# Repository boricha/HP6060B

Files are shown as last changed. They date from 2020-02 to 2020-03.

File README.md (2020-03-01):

# HP6060B
HP 6060B 3-60V/0-60A 300W SYSTEM DC ELECTRONIC LOAD  Graphic LCD Bridge
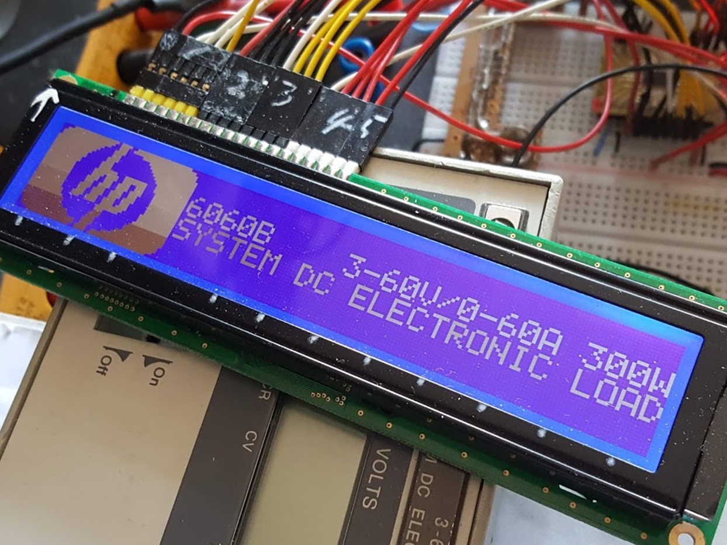
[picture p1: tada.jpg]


/*
 * $Id: main.c 3:06 PM 11/28/2019 ssk  $
 *
 * HP 6060B Graphic LCD .
 *
 * MIT License
 *
 * Copyright (c) 2019 ssk.
 *
 * Permission is hereby granted, free of charge, to any person obtaining a copy
 * of this software and associated documentation files (the "Software"), to deal
 * in the Software without restriction, including without limitation the rights
 * to use, copy, modify, merge, publish, distribute, sublicense, and/or sell
 * copies of the Software, and to permit persons to whom the Software is
 * furnished to do so, subject to the following conditions:
 *
 * The above copyright notice and this permission notice shall be included in all
 * copies or substantial portions of the Software.
 *
 * THE SOFTWARE IS PROVIDED "AS IS", WITHOUT WARRANTY OF ANY KIND, EXPRESS OR
 * IMPLIED, INCLUDING BUT NOT LIMITED TO THE WARRANTIES OF MERCHANTABILITY,
 * FITNESS FOR A PARTICULAR PURPOSE AND NONINFRINGEMENT. IN NO EVENT SHALL THE
 * AUTHORS OR COPYRIGHT HOLDERS BE LIABLE FOR ANY CLAIM, DAMAGES OR OTHER
 * LIABILITY, WHETHER IN AN ACTION OF CONTRACT, TORT OR OTHERWISE, ARISING FROM,
 * OUT OF OR IN CONNECTION WITH THE SOFTWARE OR THE USE OR OTHER DEALINGS IN THE
 * SOFTWARE.
 *
*/

<pre>
* The command was originally 10bits LSB First,
* but since the first 2 bits are always 0 and atmel SPI is 8bit system
* Accordingly 8Bits is used here
* +-----+--------------+------------------+---------------+
* |SYNC#|command field |10bit(originally) |8bit(used hear)|
* +-----+--------------+-----+------------+----------+----+
* |    0|Select LCD    |0x3f0|0b1111110000|0b11111100|0xfc|
* |    1|Unknown       |0x2e0|0b1011100000|0b10111000|0xb8|
* |    2|A Register    |0x028|0b0000101000|0b00001010|0x0a|
* |    3|B Register    |0x068|0b0001101000|0b00011010|0x1a|
* |    4|Annunciator   |0x2f0|0b1011110000|0b10111100|0xbc|
* |    5|C Register    |0x0a8|0b0010101000|0b00101010|0x2a|
* |    6|Display On/Off|0x320|0b1100100000|0b11001000|0xc8|
* +-----+--------------+------------------+---------------+
* Remembering that bits are transmitted from least significant bit (LSB) to most significant bit (MSB),
* aka. LSB First
</pre>

## Digial Waveform
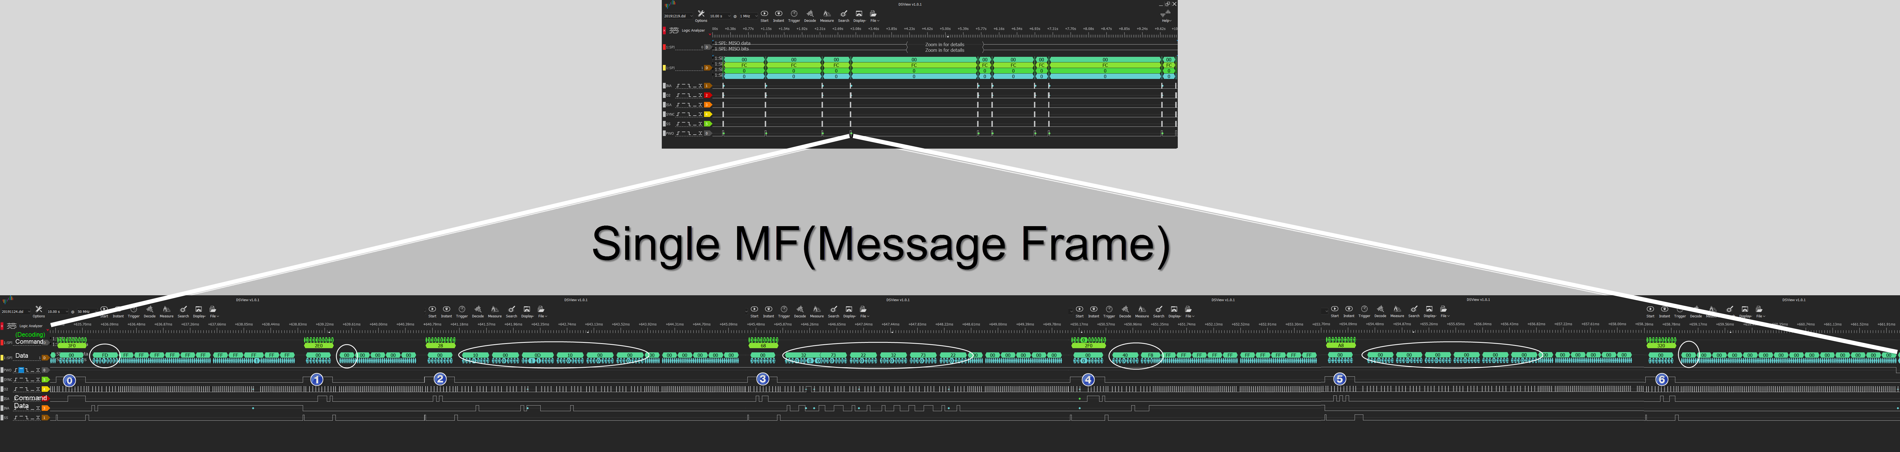
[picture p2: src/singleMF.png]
        
## Message Frame Structure(MF)
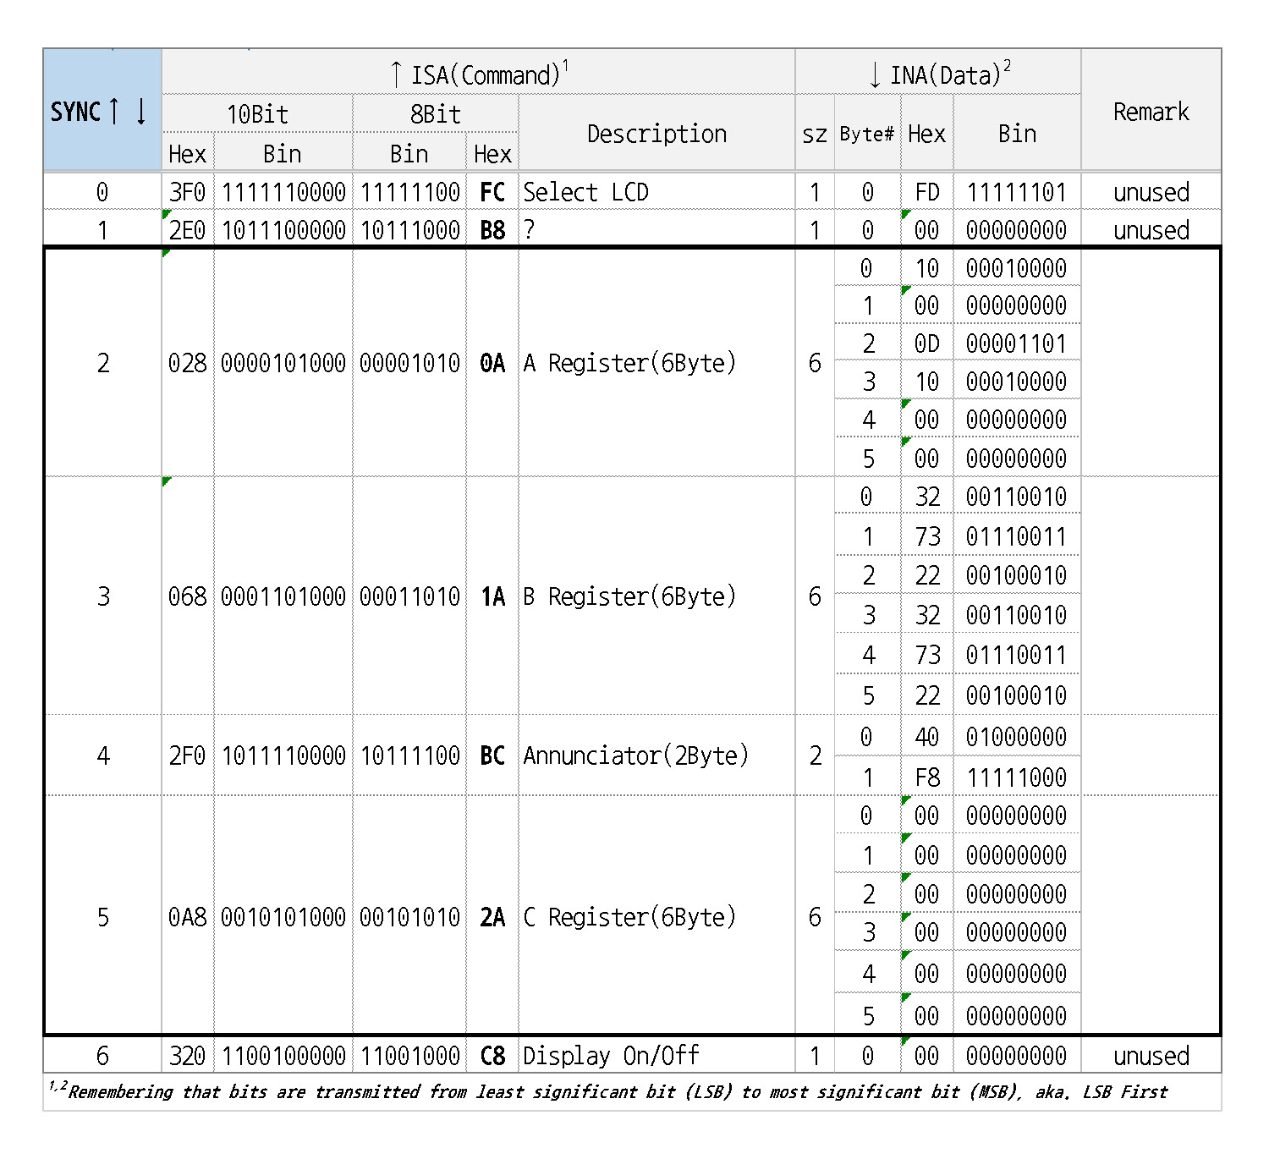
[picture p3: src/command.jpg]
   
## Modeling Event Based Behavior
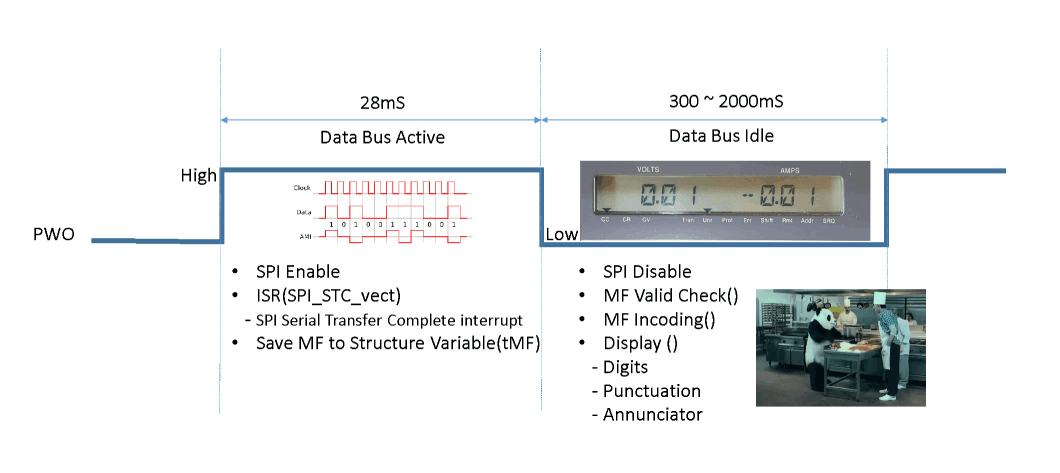
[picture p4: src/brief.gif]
   
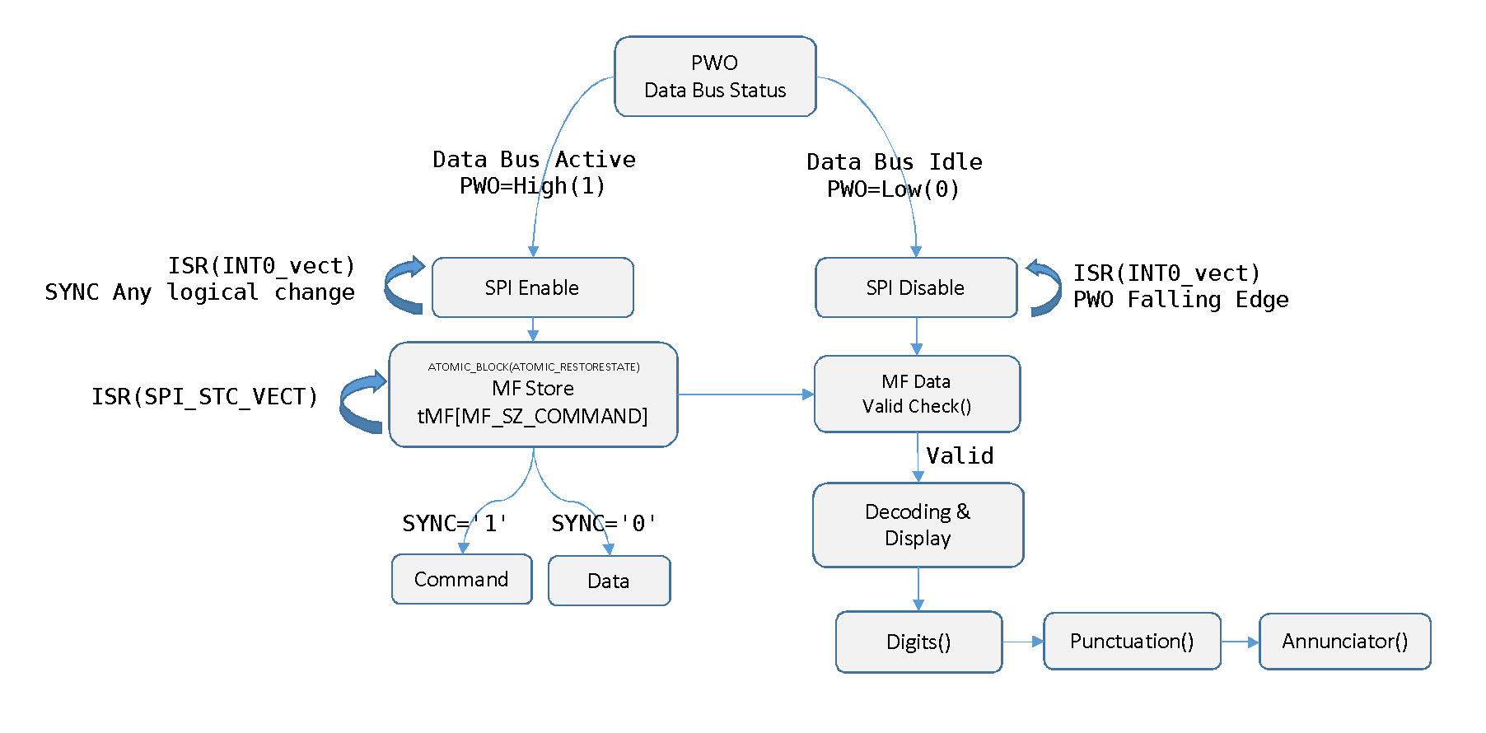
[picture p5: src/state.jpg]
   
## Schematics
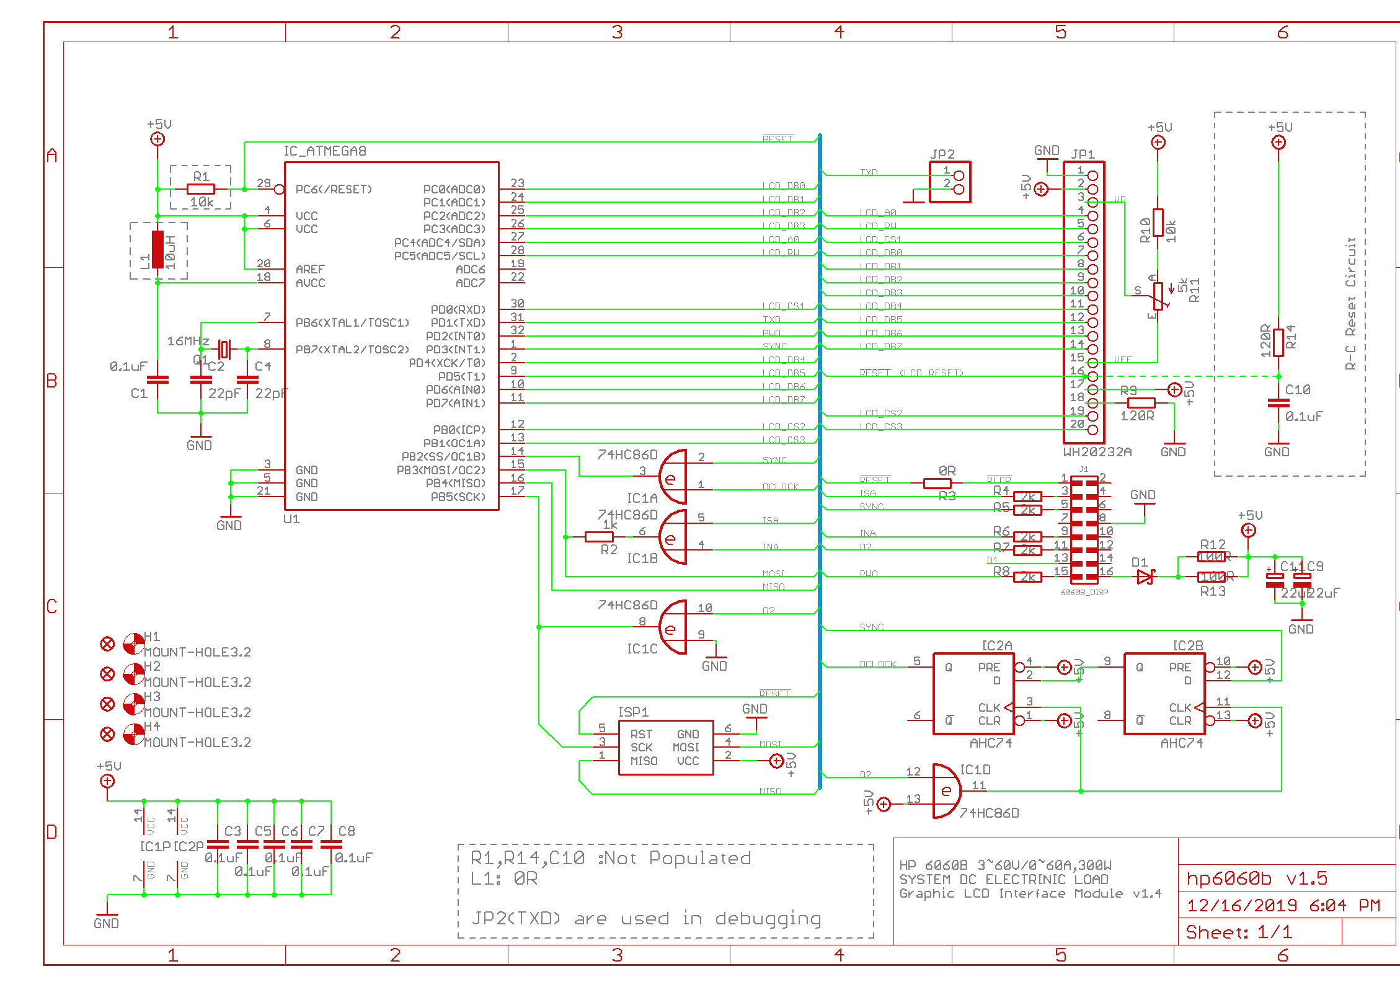
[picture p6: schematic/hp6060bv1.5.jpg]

## BOM(Bill of materials)
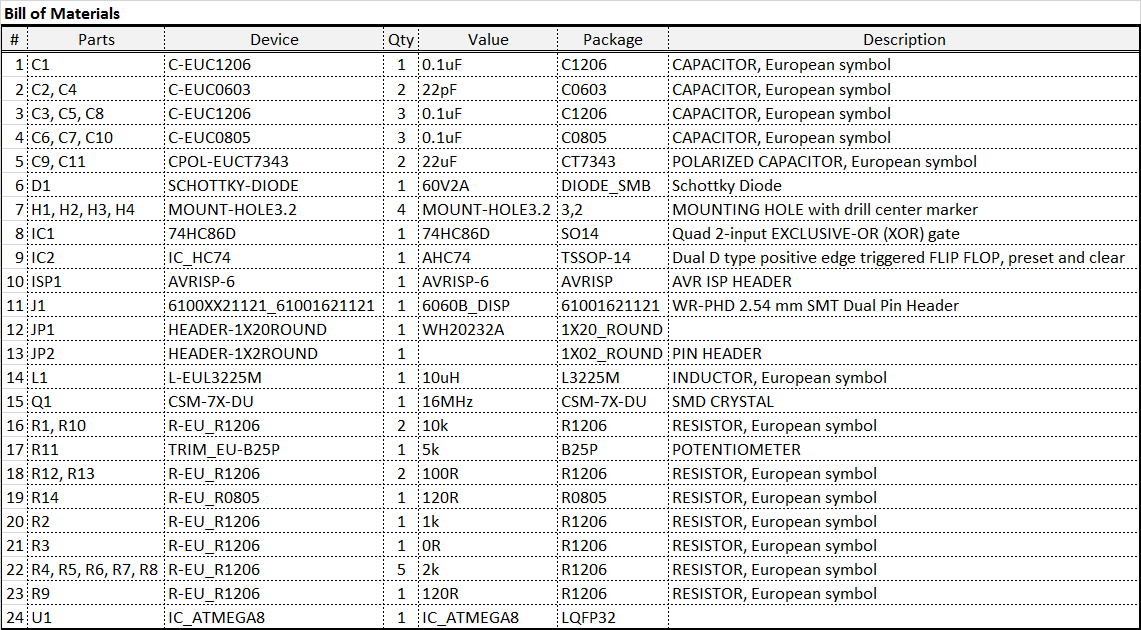
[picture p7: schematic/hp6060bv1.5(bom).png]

## PCB(top/bottom)
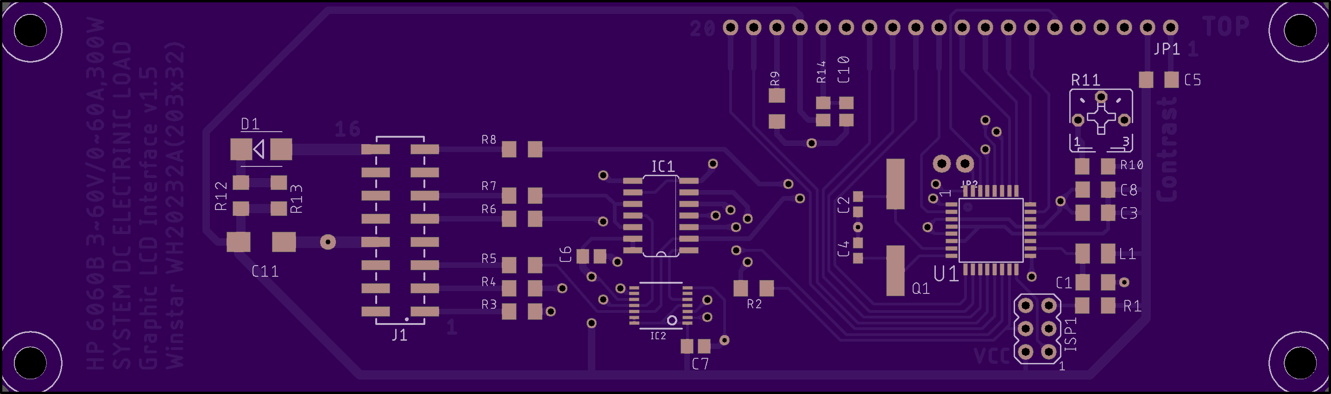
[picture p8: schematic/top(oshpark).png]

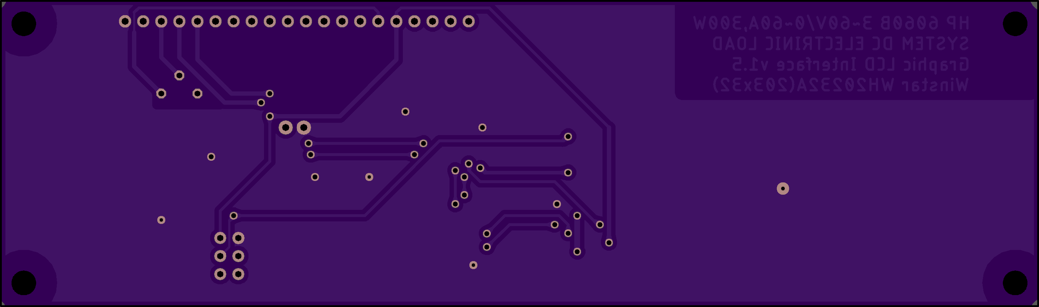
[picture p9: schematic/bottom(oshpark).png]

##
https://cafe.naver.com/carroty/337725
## Special thanks to: :+1: 
[LED display for HP 3457A multimeter - I did it :-)]<BR>
https://www.eevblog.com/forum/projects/led-display-for-hp-3457a-multimeter-i-did-it-)/ <BR>
I adapted this Aricle.  

述而不作.

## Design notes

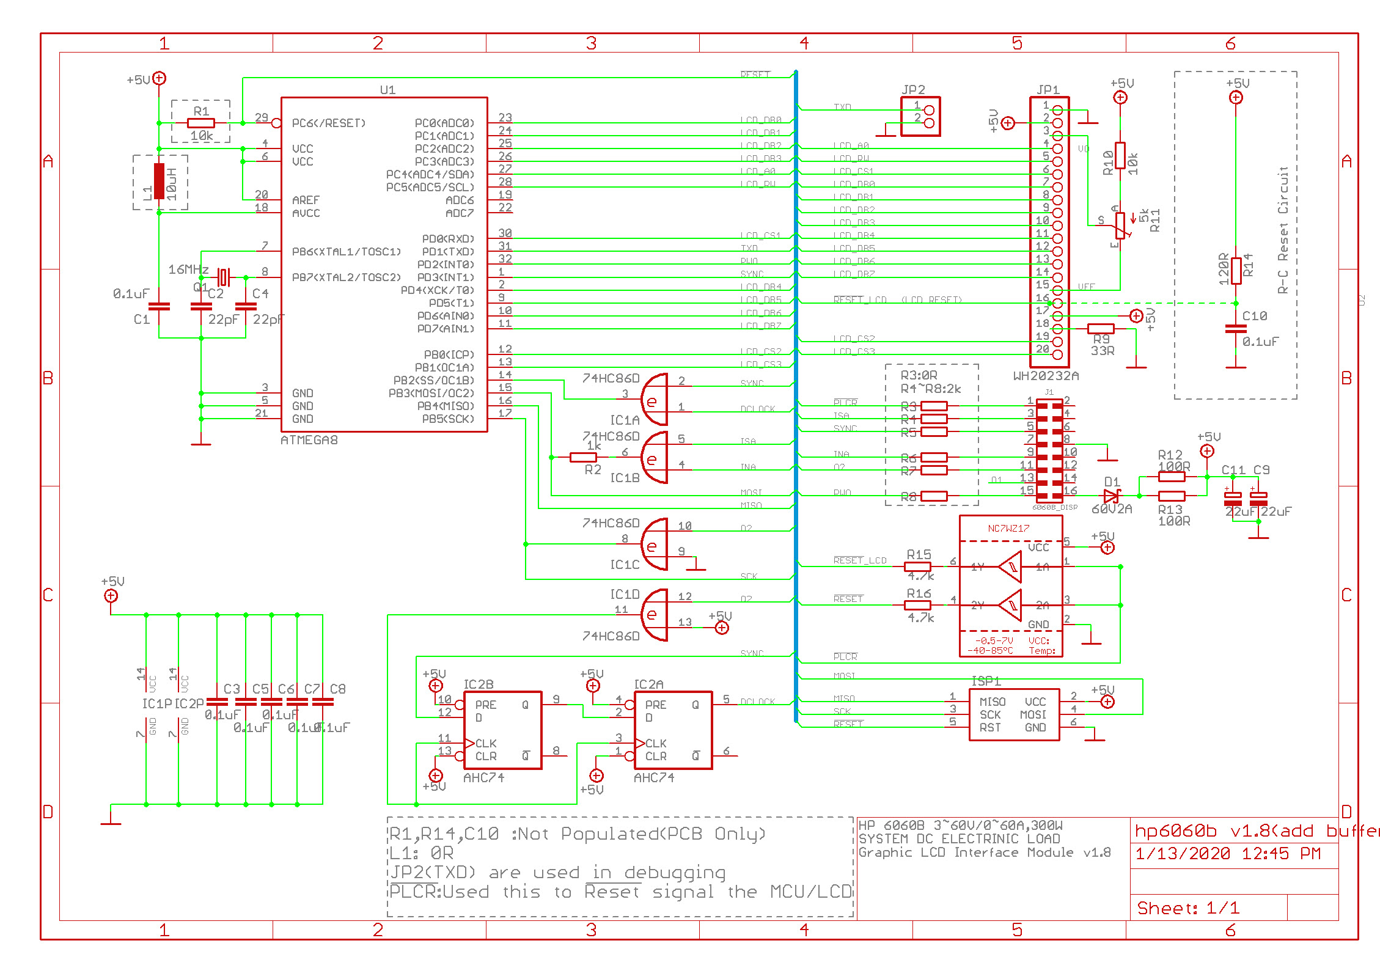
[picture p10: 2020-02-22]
schematic/hp6060bv1.8(add buffer).jpg

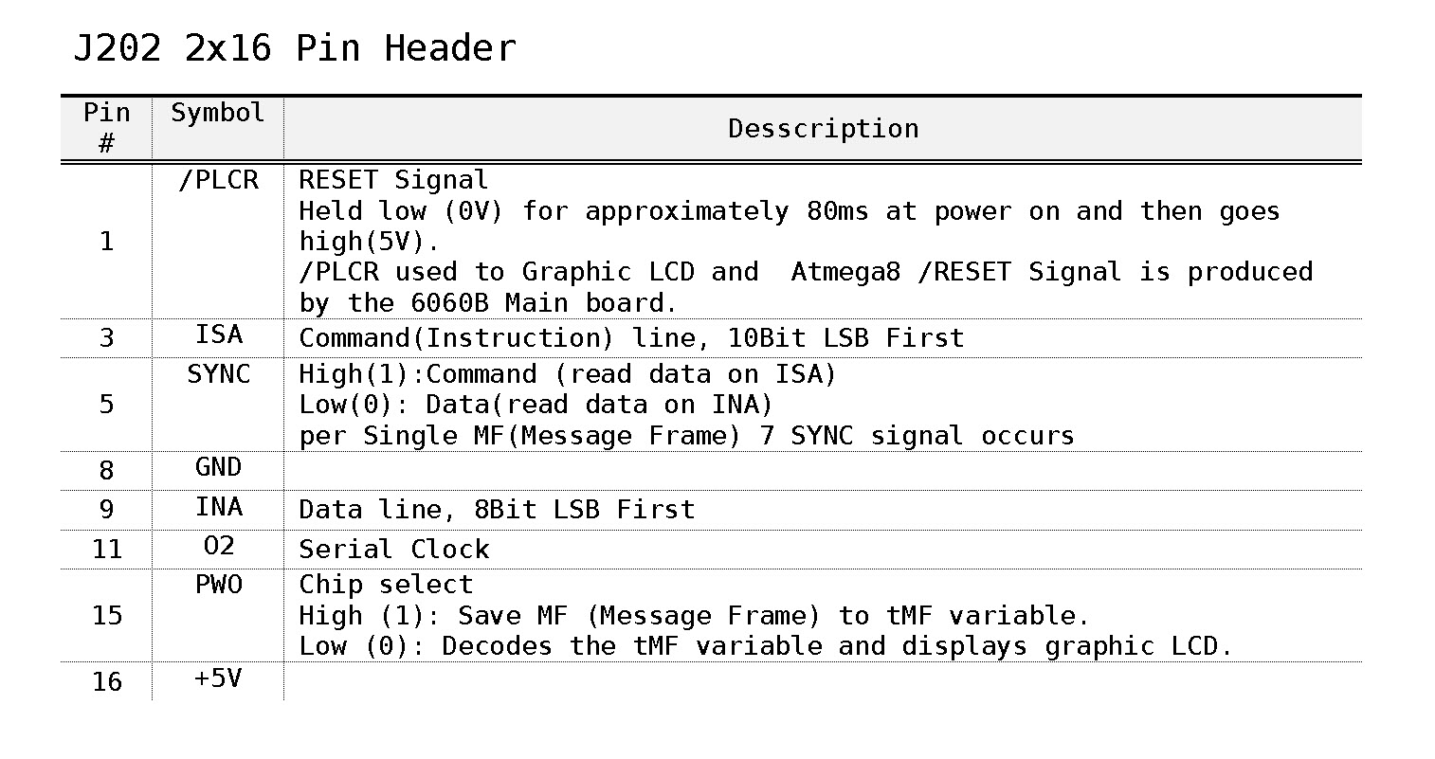
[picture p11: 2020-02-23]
src/pinout.jpg

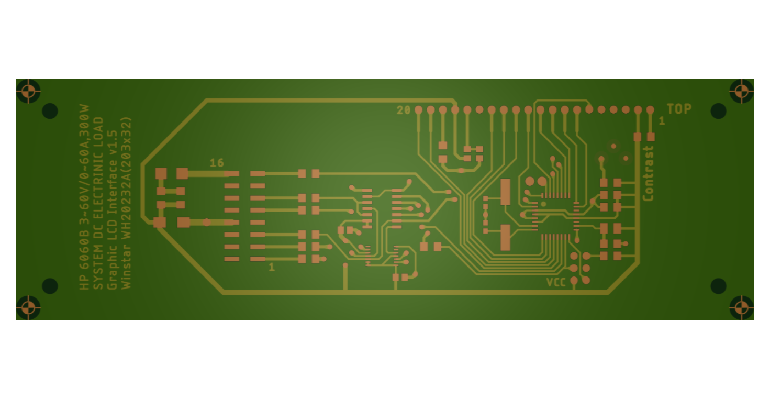
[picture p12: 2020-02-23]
schematic/top.png

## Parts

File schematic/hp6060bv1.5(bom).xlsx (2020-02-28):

Bill of Materials
# | Parts | Device | Qty | Value | Package | Description
1 | C1 | C-EUC1206 | 1 | 0.1uF | C1206 | CAPACITOR, European symbol
2 | C2, C4 | C-EUC0603 | 2 | 22pF | C0603 | CAPACITOR, European symbol
3 | C3, C5, C8 | C-EUC1206 | 3 | 0.1uF | C1206 | CAPACITOR, European symbol
4 | C6, C7, C10 | C-EUC0805 | 3 | 0.1uF | C0805 | CAPACITOR, European symbol
5 | C9, C11 | CPOL-EUCT7343 | 2 | 22uF | CT7343 | POLARIZED CAPACITOR, European symbol
6 | D1 | SCHOTTKY-DIODE | 1 | 60V2A | DIODE_SMB | Schottky Diode
7 | H1, H2, H3, H4 | MOUNT-HOLE3.2 | 4 | MOUNT-HOLE3.2 | 3,2 | MOUNTING HOLE with drill center marker
8 | IC1 | 74HC86D | 1 | 74HC86D | SO14 | Quad 2-input EXCLUSIVE-OR (XOR) gate
9 | IC2 | IC_HC74 | 1 | AHC74 | TSSOP-14 | Dual D type positive edge triggered FLIP FLOP, preset and clear
10 | ISP1 | AVRISP-6 | 1 | AVRISP-6 | AVRISP | AVR ISP HEADER
11 | J1 | 6100XX21121_61001621121 | 1 | 6060B_DISP | 61001621121 | WR-PHD 2.54 mm SMT Dual Pin Header
12 | JP1 | HEADER-1X20ROUND | 1 | WH20232A | 1X20_ROUND
13 | JP2 | HEADER-1X2ROUND | 1 |  | 1X02_ROUND | PIN HEADER
14 | L1 | L-EUL3225M | 1 | 10uH | L3225M | INDUCTOR, European symbol
15 | Q1 | CSM-7X-DU | 1 | 16MHz | CSM-7X-DU | SMD CRYSTAL
16 | R1, R10 | R-EU_R1206 | 2 | 10k | R1206 | RESISTOR, European symbol
17 | R11 | TRIM_EU-B25P | 1 | 5k | B25P | POTENTIOMETER
18 | R12, R13 | R-EU_R1206 | 2 | 100R | R1206 | RESISTOR, European symbol
19 | R14 | R-EU_R0805 | 1 | 120R | R0805 | RESISTOR, European symbol
20 | R2 | R-EU_R1206 | 1 | 1k | R1206 | RESISTOR, European symbol
21 | R3 | R-EU_R1206 | 1 | 0R | R1206 | RESISTOR, European symbol
22 | R4, R5, R6, R7, R8 | R-EU_R1206 | 5 | 2k | R1206 | RESISTOR, European symbol
23 | R9 | R-EU_R1206 | 1 | 120R | R1206 | RESISTOR, European symbol
24 | U1 | IC_ATMEGA8 | 1 | IC_ATMEGA8 | LQFP32

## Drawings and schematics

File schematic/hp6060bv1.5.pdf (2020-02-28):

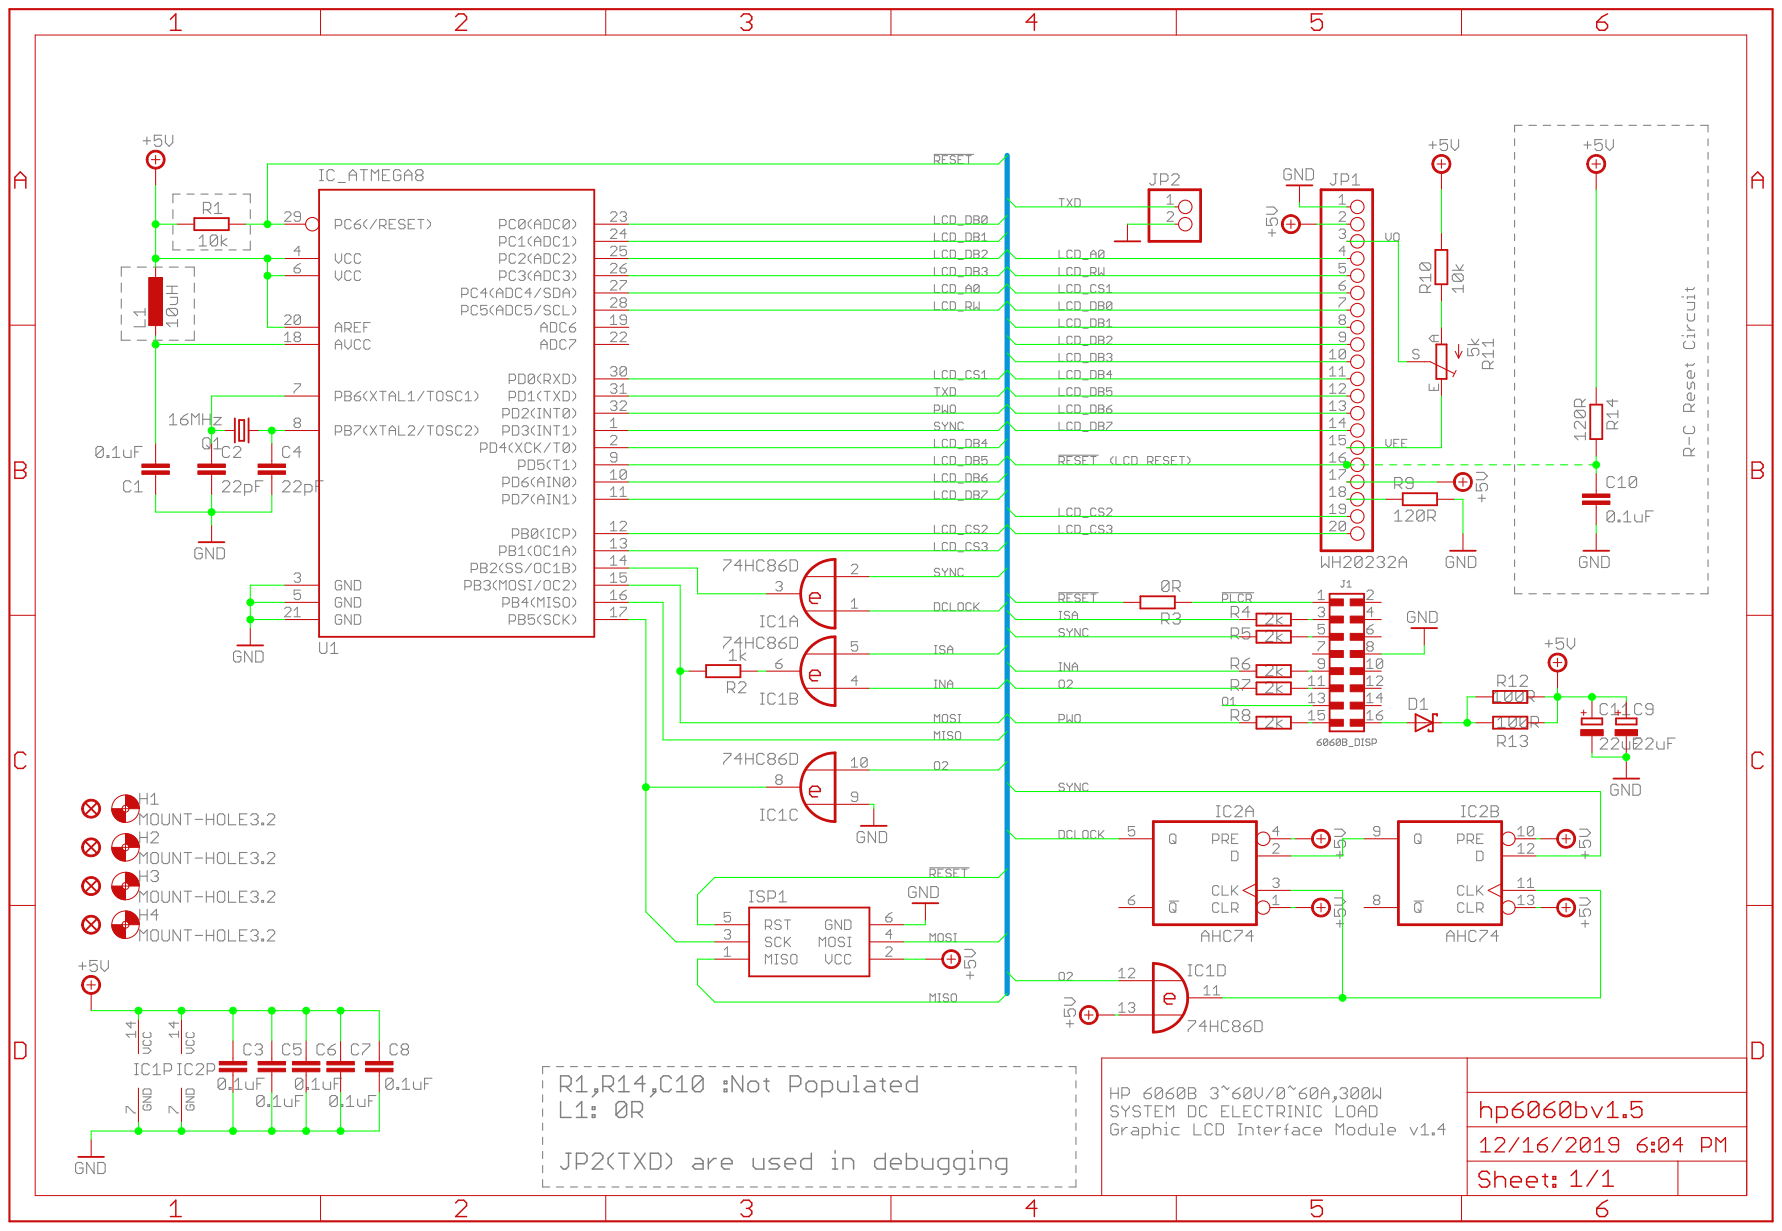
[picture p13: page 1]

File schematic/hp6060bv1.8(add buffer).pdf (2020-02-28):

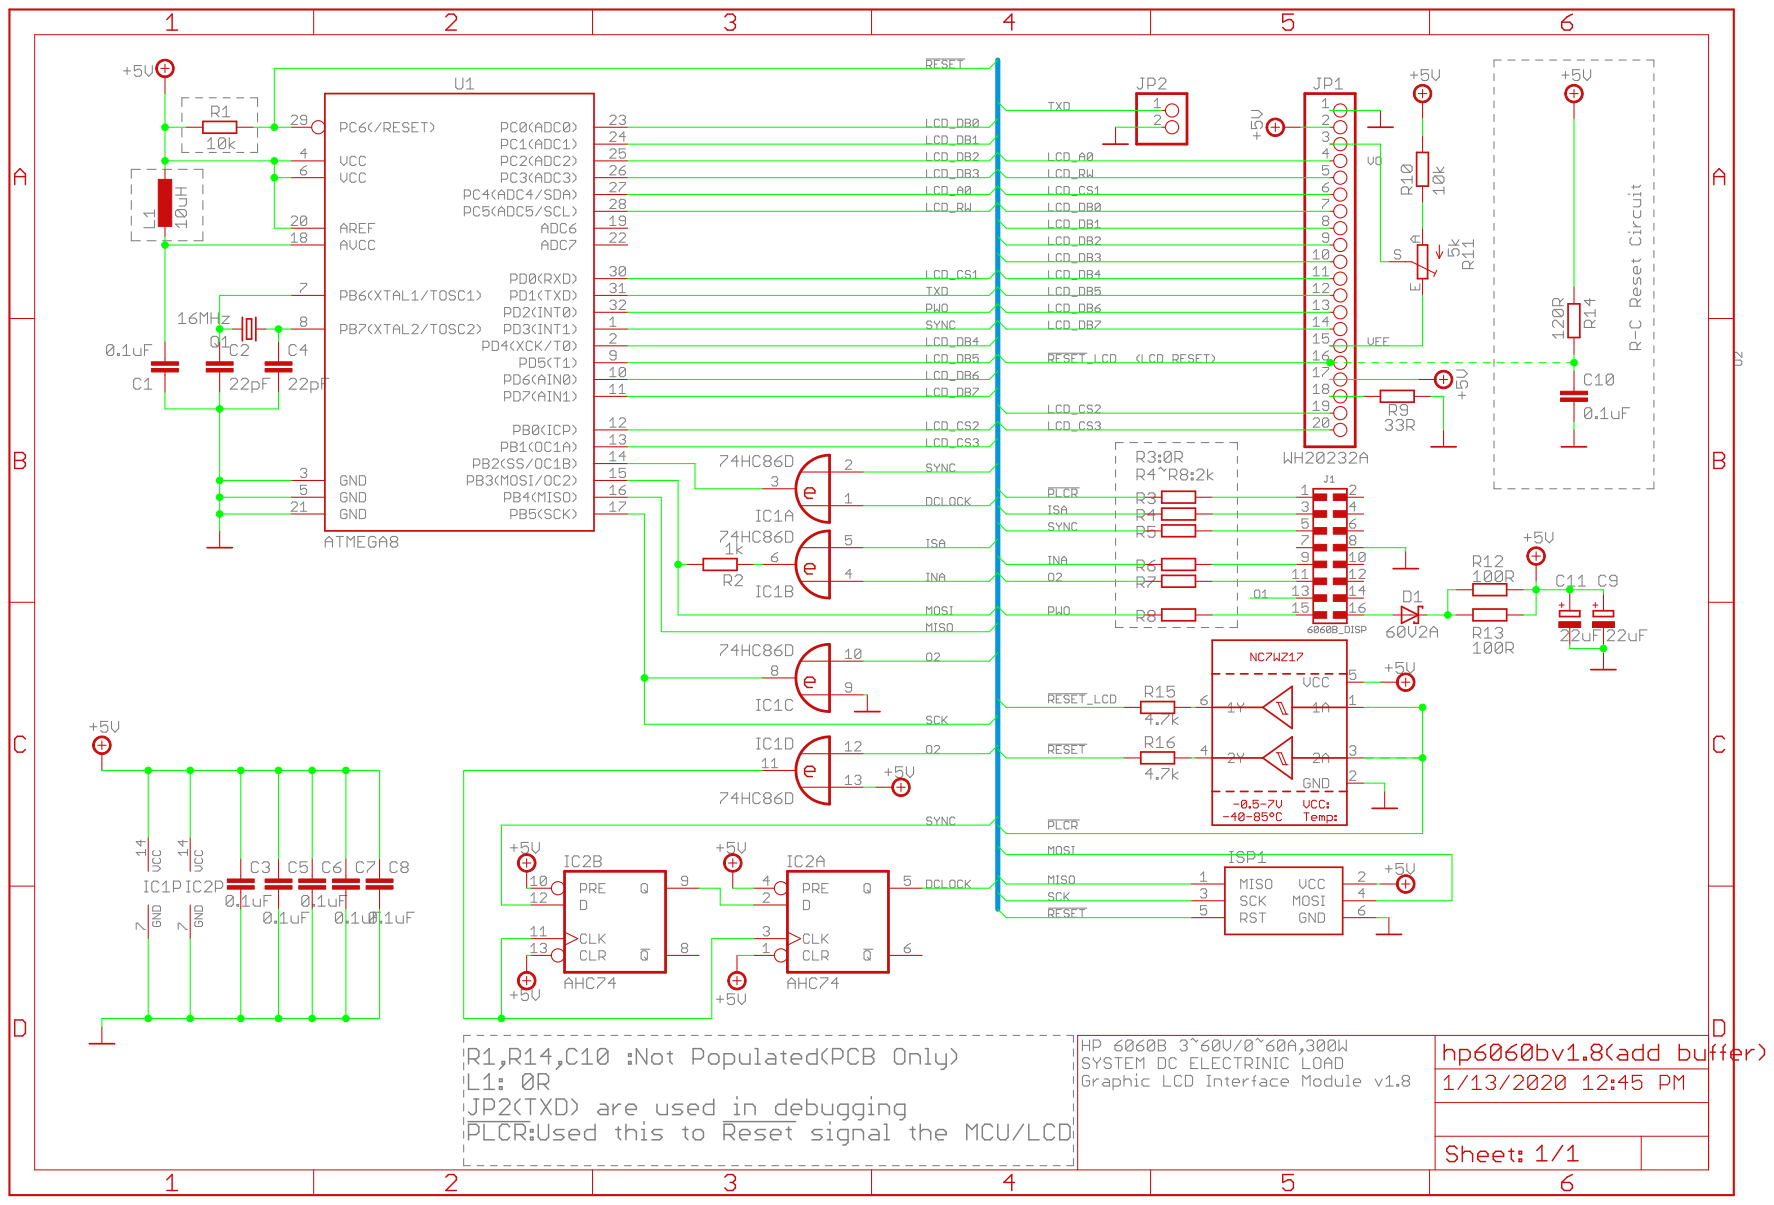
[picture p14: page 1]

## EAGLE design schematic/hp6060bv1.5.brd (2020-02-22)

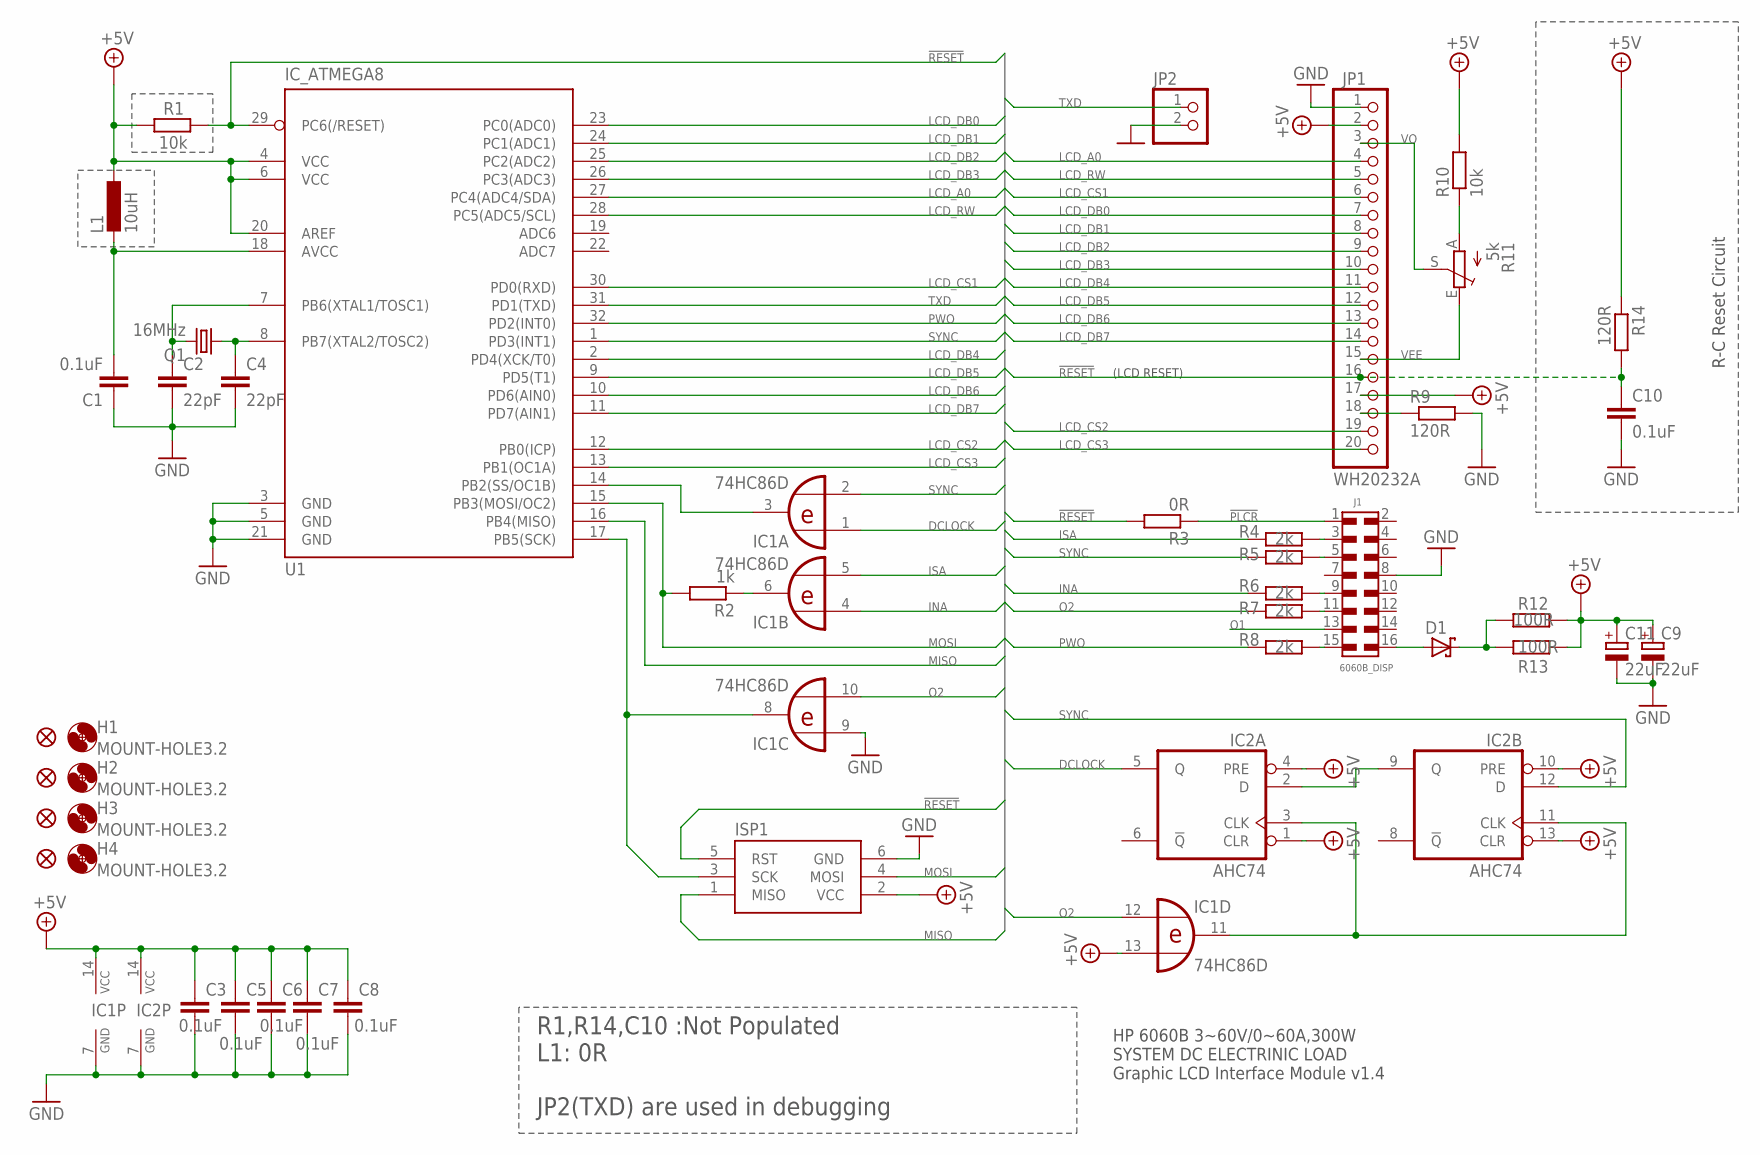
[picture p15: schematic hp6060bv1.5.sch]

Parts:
C1, C3, C5, C8: 0.1uF; C1206
C2, C4: 22pF; C0603
C6, C7, C10: 0.1uF; C0805
C9, C11: 22uF; CT7343
D1: SCHOTTKY-DIODE; DIODE_SMB
FID1, FID2, FID3, FID4: PCB_FIDUCIALROUND; PASS-ROUND
H1, H2, H3, H4: MOUNT-HOLE3.2; 3,2
IC1: 74HC86D; SO14
IC2: AHC74; TSSOP-14
ISP1: AVRISP-6; AVRISP
J1: 6060B_DISP; 61001621121
JP1: WH20232A; 1X20_ROUND
JP2: HEADER-1X2ROUND; 1X02_ROUND
L1: 10uH; L3225M
Q1: 16MHz; CSM-7X-DU
R1, R10: 10k; R1206
R2: 1k; R1206
R3: 0R; R1206
R4, R5, R6, R7, R8: 2k; R1206
R9: 120R; R1206
R11: 5k; B25P
R12, R13: 100R; R1206
R14: 120R; R0805
U1: IC_ATMEGA8; LQFP32

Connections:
!PLCR: J1.1, R3.1
!RESET: C10.1, ISP1.5 (RST), JP1.16, R1.1, R3.2, R14.2, U1.29 (PC6(/RESET))
!SS: IC1.3 (O), U1.14 (PB2(SS/OC1B))
+5V: C3.1, C5.1, C6.1, C7.1, C8.1, C9.+, C11.+, IC1.13 (I1), IC1.14 (VCC), IC2.1 (CLR), IC2.4 (PRE), IC2.10 (PRE), IC2.13 (CLR), IC2.14 (VCC), ISP1.2 (VCC), JP1.2, JP1.17, L1.1, R1.2, R10.2, R12.2, R13.2, R14.1, U1.4 (VCC), U1.6 (VCC), U1.20 (AREF)
AVCC: C1.2, L1.2, U1.18 (AVCC)
DCLOCK: IC1.1 (I0), IC2.5 (Q)
GND: C1.1, C2.2, C3.2, C4.2, C5.2, C6.2, C7.2, C8.2, C9.-, C10.2, C11.-, IC1.7 (GND), IC1.9 (I0), IC2.7 (GND), ISP1.6 (GND), J1.8, JP1.1, JP2.2, R9.2, U1.3 (GND), U1.5 (GND), U1.21 (GND)
INA: IC1.4 (I0), R6.1
ISA: IC1.5 (I1), R4.1
K: JP1.18, R9.1
LCD_A0: JP1.4, U1.27 (PC4(ADC4/SDA))
LCD_CS1: JP1.6, U1.30 (PD0(RXD))
LCD_CS2: JP1.19, U1.12 (PB0(ICP))
LCD_CS3: JP1.20, U1.13 (PB1(OC1A))
LCD_DB0: JP1.7, U1.23 (PC0(ADC0))
LCD_DB1: JP1.8, U1.24 (PC1(ADC1))
LCD_DB2: JP1.9, U1.25 (PC2(ADC2))
LCD_DB3: JP1.10, U1.26 (PC3(ADC3))
LCD_DB4: JP1.11, U1.2 (PD4(XCK/T0))
LCD_DB5: JP1.12, U1.9 (PD5(T1))
LCD_DB6: JP1.13, U1.10 (PD6(AIN0))
LCD_DB7: JP1.14, U1.11 (PD7(AIN1))
LCD_RW: JP1.5, U1.28 (PC5(ADC5/SCL))
MISO: ISP1.1 (MISO), U1.16 (PB4(MISO))
MOSI: ISP1.4 (MOSI), R2.2, U1.15 (PB3(MOSI/OC2))
unnamed: IC1.11 (O), IC2.3 (CLK), IC2.11 (CLK)
unnamed: D1.A (C), J1.16
unnamed: R10.1, R11.A
unnamed: J1.3, R4.2
unnamed: J1.5, R5.2
unnamed: D1.C (A), R12.1, R13.1
unnamed: J1.9, R6.2
unnamed: J1.11, R7.2
unnamed: IC2.2 (D), IC2.9 (Q)
unnamed: J1.15, R8.2
unnamed: IC1.6 (O), R2.1
O1: J1.13
O2: IC1.10 (I1), IC1.12 (I0), R7.1
PWO: R8.1, U1.32 (PD2(INT0))
SCK: IC1.8 (O), ISP1.3 (SCK), U1.17 (PB5(SCK))
SYNC: IC1.2 (I1), IC2.12 (D), R5.1, U1.1 (PD3(INT1))
TXD: JP2.1, U1.31 (PD1(TXD))
VEE: JP1.15, R11.E
VO: JP1.3, R11.S
XTAL1: C2.1, Q1.2, U1.7 (PB6(XTAL1/TOSC1))
XTAL2: C4.1, Q1.1, U1.8 (PB7(XTAL2/TOSC2))

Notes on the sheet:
(LCD RESET)
R-C Reset Circuit
R1,R14,C10 :Not Populated L1: 0R JP2(TXD) are used in debugging
HP 6060B 3~60V/0~60A,300W SYSTEM DC ELECTRINIC LOAD Graphic LCD Interface Module v1.4

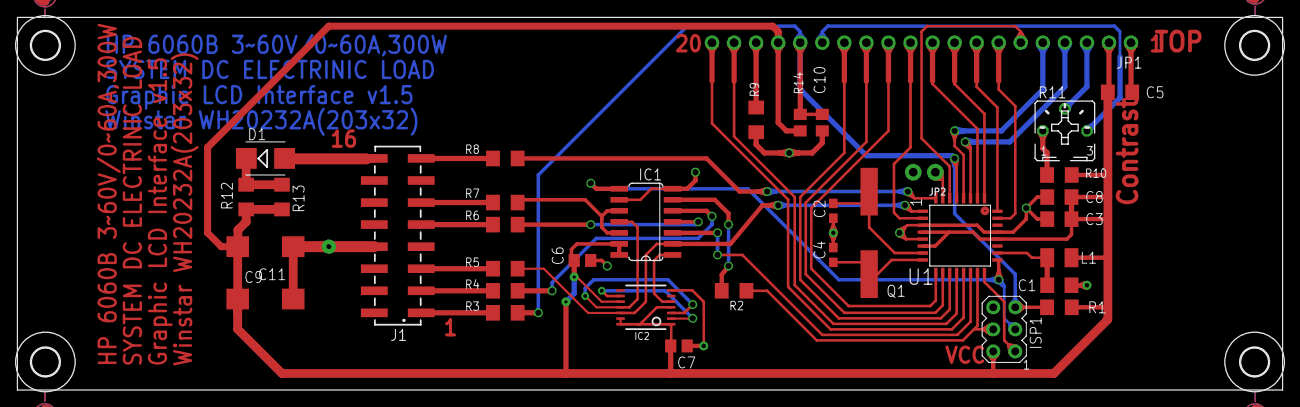
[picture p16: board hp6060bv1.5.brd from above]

Board: 2 copper layers, 145.7 x 42.9 mm, 43 parts (1 on the bottom side), 45 nets.

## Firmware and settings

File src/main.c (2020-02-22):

/*
 * $Id: main.c 3:06 PM 11/28/2019 ssk  $
 *
 * HP 6060B Graphic LCD .
 *
 * MIT License
 *
 * Copyright (c) 2019 ssk.
 *
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
*/
#include <avr/io.h>
#include <avr/interrupt.h>
#include <avr/wdt.h>
#include <util/delay.h>
#include <util/atomic.h>
#include <string.h>           // memset
#include "sbn166g.h"
#include "glcd.h"
#include "hp6060b.h"
#include "spi.h"
#include "fonts/allfonts.h"
#include "bitmaps/allbitmaps.h"

static void setup(void);
static void timer1_init(void);
static void welcome(void);

static void MF_InitFrameBuffer(void);
static void MF_DisplayDigit(void);
static void MF_DisplayPunctuation(void);
static void MF_DisplayAnnunciator(void);
static uint8_t MF_DigitLookup(uint8_t data);
static uint8_t MF_PunctuationLookup(uint8_t data);
static uint8_t MF_isValid(void);

tMessageFrame tMF[MF_SZ_COMMAND];

volatile uint16_t milliseconds=0;

#ifdef __DEBUG_MODE__
#include <stdio.h>            // FILE
#include "uart_simple.h"
FILE mystdout = FDEV_SETUP_STREAM(uart_putchar, NULL, _FDEV_SETUP_WRITE);
uint16_t lastActiveTime;
#endif

int main(void)
{
  /*
   * Enable the watchdog with a period of 2s
   * Watchdog Timer is initially disabled,
   * but can be enabled by writing the WDE bit to 1 without any restriction.
   */
  wdt_enable(WDTO_2S);

  setup();
  MF_InitFrameBuffer();

  sei();
#ifdef __DEBUG_MODE__
  stdout = &mystdout;
  uart_init();
#endif

  wdt_reset();
  welcome();
  wdt_reset();
  
  while(1)
  {
    /*
     * when PWO logic 'L' (data bus idle) Refreshes the display
     */
    //if((milliseconds & 0x200) && isDataBusIdle())
    if(isDataBusIdle())
    {
      if(MF_isValid())
      {
#ifdef __DEBUG_MODE__
        lastActiveTime = milliseconds;
#endif
        MF_DisplayDigit();
        MF_DisplayPunctuation();
        MF_DisplayAnnunciator();
        MF_InitFrameBuffer();
#ifdef __DEBUG_MODE__
        printf("lead time(ms) = [%u]\r\n",milliseconds-lastActiveTime);
#endif
      }
      wdt_reset();
    }
  }
  return 0;
}

static void welcome(void)
{
  glcd_clear(0x00);
  glcd_selectfont(lcd14_15bi_16x17, LCD_DOT_SET, FONT_ENGLISH,0);
  glcd_gotoxy(0,8); glcd_puts_P("************");

  glcd_selectfont(system_5_5x7, LCD_DOT_SET, FONT_ENGLISH,12);
  glcd_gotoxy(4 ,24);
  for(uint8_t i=0; i<12; i++)
  {
    glcd_putc(MF_ANNUNCIATOR_CHAR);
  }
  
  /*
   * Display check Puase roughly 500mS (0.5s)
   * the Interrupts routine will run without pausing.
   */
  while(1)
  {
    if(milliseconds & 0x200)
    {
      break;
    }
  }
  wdt_reset();

  glcd_clear(0x00);
  glcd_bitmap(hp52x32, 0,0,LCD_DOT_SET);
  glcd_selectfont(system_5_5x7, LCD_DOT_SET, FONT_ENGLISH,1);
  glcd_gotoxy(53,8);  glcd_puts_P("6060B    3-60V/0-60A 300W");
  glcd_gotoxy(53,16); glcd_puts_P("SYSTEM DC ELECTRONIC LOAD");
  
  /*
   * At start up, a momentary (1 second) welcome screen display
   * the Interrupts routine will run without pausing.
   */
  while(1)
  {
    if(milliseconds & 0x400)
    {
      break;
    }
  }  
  wdt_reset();
  glcd_clear(0x00);
}

static void timer1_init(void)
{
  // Timer 0 interrupt gets called every 0.001sec(1ms)
  TCCR1B =  _BV(WGM12) |   // CTC mode(mode:4)
            _BV(CS10);     // clkI/O/1 (no prescaler)
            
  OCR1A  |=  15999;        //(0.001    / (1 / (16000000 / 1)) - 1)
  TIMSK  |= _BV(OCIE1A);
}

/*
* Global variable wrapper.
*
* you may need to change some global values at run time
* global Variable  must be managed one place
*
*/

static void setup(void)
{
/*
* configure external interrupts
*
* INT0(The falling edge)  , PWO :global chip select
* INT1(Any logical change), SYNC:1=read data on ISA(command)
*                                0=read data on INA(data)
*/
  MCUCR |= _BV(ISC01) |      // INT0, The falling edge
           _BV(ISC10);       // INT1, Any logical change

  // clear external interrupts flags INT1, INT0
  GIFR  |= _BV(INTF1) | _BV(INTF0);

  //  enable external interrupts INT1, INT0
  GICR  |= _BV(INT1)  | _BV(INT0);

  // GPIO initialize
  CTRL_DDR  &= ~(_BV(CTRL_PWO) | CTRL_SYNC);  // input
  CTRL_PORT |=  (_BV(CTRL_PWO) | CTRL_SYNC);  // enable internal pull-up register

  timer1_init();
  glcd_init();

  // SPI in slave mode (LSB fist)
  spi_init(SPI_MODE_0, SPI_LSB, SPI_INTERRUPT, SPI_SLAVE);
}

static void MF_InitFrameBuffer(void)
{
  memset(&tMF, 0, sizeof(tMF));
}

static uint8_t MF_isValid(void)
{

  if((tMF[MF_IDX_REGISTER_A].valid  == MF_DATA_VALID) &&
     (tMF[MF_IDX_REGISTER_B].valid  == MF_DATA_VALID) &&
     (tMF[MF_IDX_REGISTER_C].valid  == MF_DATA_VALID) &&
     (tMF[MF_IDX_ANNUNCIATOR].valid == MF_DATA_VALID))
  {
    return MF_DATA_VALID;
  }
  return MF_DATA_INVALID;

}

// number or character
static void MF_DisplayDigit(void)
{
  uint8_t data;

  glcd_selectfont(lcd14_15bi_16x17, LCD_DOT_SET, FONT_ENGLISH,0);
  glcd_gotoxy(0,8);
  for(uint8_t i=0; i<MF_MAX_DIGIT; i+=2)
  {
    // even digit
    data = ((tMF[MF_IDX_REGISTER_A].data[i/2] & 0xf0) >> 4)|
            (tMF[MF_IDX_REGISTER_B].data[i/2] & 0x30)      |
           ((tMF[MF_IDX_REGISTER_C].data[i/2] & 0x10) << 2);
    glcd_putc(MF_DigitLookup(data));

    // odd digit
    data =  (tMF[MF_IDX_REGISTER_A].data[i/2] & 0x0f)      |
           ((tMF[MF_IDX_REGISTER_B].data[i/2] & 0x03) << 4)|
           ((tMF[MF_IDX_REGISTER_C].data[i/2] & 0x01) << 6);
    glcd_putc(MF_DigitLookup(data));
  }
}

// Punctuation ('.', ',', ':')
static void MF_DisplayPunctuation(void)
{
  uint8_t data;

  glcd_selectfont(hp6060b_punct, LCD_DOT_SET, FONT_ENGLISH,15);
  glcd_gotoxy(14,16);
  for(uint8_t i=0; i<MF_MAX_DIGIT; i+=2)
  {
    // even digit punctuation
    data = (tMF[MF_IDX_REGISTER_B].data[i/2] & 0xc0);
    glcd_putc(MF_PunctuationLookup(data));

    // odd digit punctuation
    data = (tMF[MF_IDX_REGISTER_B].data[i/2] & 0x0c);
    glcd_putc(MF_PunctuationLookup(data));
  }
}

static void MF_DisplayAnnunciator(void)
{
  uint16_t bitmask;

  bitmask = (tMF[MF_IDX_ANNUNCIATOR].data[0] << 8) | (tMF[MF_IDX_ANNUNCIATOR].data[1]);

  glcd_selectfont(system_5_5x7, LCD_DOT_SET, FONT_ENGLISH,12);
  glcd_gotoxy(4 ,24);
  for(uint8_t i=MF_MAX_DIGIT; i--;)
  {
    if(bitmask & _BV(i))
    {
      glcd_putc(MF_ANNUNCIATOR_CHAR);
    }
    else
    {
      glcd_putc(' ');
    }
  }
}

/*
* Lookup table for non standard characters
*/
static uint8_t MF_DigitLookup(uint8_t data)
{
  if(data == 00) data = '*';   // '@' -> '*';
  else if(data < 0x20)  data = data + '@';   // '@ABCDEFGHIJKLMNOPQRSTUVWXYZ'
  else if(data == 0x2c) data = '<';    // should be a left pointing arrow
  else if(data == 0x2e) data = '>';    // should be a right pointing arrow
  else if(data == 0x3a) data = '*';    // should be the 14 segments lit
  else if(data <  0x40) data = data;   // ';<=>?'
  else if(data <  0x46) data = data - 'A' + 'a'; // 'abcde'
//else if(data == 0x40) data = '/';    // should be a 90° counter clockwise rotated 'T'
//else if(data == 0x46) data = '/';    // 46~4b this one and the 5 following should represent a hourglass
//else if(data == 0x47) data = '/';
//else if(data == 0x48) data = '/';
//else if(data == 0x49) data = '/';
//else if(data == 0x4a) data = '/';
//else if(data == 0x4b) data = '/';
//else if(data == 0x4c) data = '/';    // 'µ'
//else if(data == 0x4d) data = '/';    // "not equal"
//else if(data == 0x4e) data = '/';    // sigma sign
//else if(data == 0x4f) data = '/';
  else
  {
    data = '?'; //unknown
  }
  return data;
}
/*
* Lookup table for Punctuation characters
*/
static uint8_t MF_PunctuationLookup(uint8_t data)
{
  switch(data)
  {
    case 0x40:        // even digits
    case 0x04:        // odd digits
         data = MF_PUNCT_DOT;
         break;

    case 0x80:
    case 0x08:
         data = MF_PUNCT_COLON;
         break;

    case 0xc0:
    case 0x0c:
         data = MF_PUNCT_COMMA;
         break;

    default:
         data = MF_PUNCT_NONE;
         break;
  }
  return data;
}
/**********************
 * Interrupt routines *
 **********************/
ISR(TIMER1_COMPA_vect)
{
  ++milliseconds;
}
/*
* External interrupt 0(PWO Falling Edge)
*
* PWO:used to detect the end of the Chip Select of the display
* PWO Logic Low(1) - SPI Data bus Idle(SPI stop)
*/
ISR(INT0_vect)
{
  spi_disable();
}
/*
* External interrupt 1(SYNC Any logical change)
*
* SYNC:used to enable the SPI when the SYNC line from the 6060B changes state
* "1":command(ISA line), "0":data(INA line)
*/
ISR(INT1_vect)
{
  if(isDataBusActive())
  {
    spi_enable();
  }
}
/*
* SPI Serial Transfer Complete interrupt
*
* stores unprocessed data(Message Frame consists of 7 commands)
*
* idxCmd : current command index
* szData : data Size(one or more, max 6 byte)
* data   : command or data that corresponding to the command
*/
ISR(SPI_STC_vect)
{
  static uint8_t idxCmd = 0;
  static uint8_t szData = 0;
  uint8_t data;

  ATOMIC_BLOCK(ATOMIC_RESTORESTATE)
  {
    data = SPDR;

    if(isCommand())
    {
      /*
       * if SYNC Logic High(1), command field in the message frame(from ISA)
       */
      switch(data)
      {
        case MF_REGISTER_A:
             idxCmd = MF_IDX_REGISTER_A;
             szData = MF_SZ_REGISTER_A;
             break;

        case MF_REGISTER_B:
             idxCmd = MF_IDX_REGISTER_B;
             szData = MF_SZ_REGISTER_B;
             break;

        case MF_REGISTER_C:
             idxCmd = MF_IDX_REGISTER_C;
             szData = MF_SZ_REGISTER_C;
             break;

        case MF_ANNUNCIATOR:
             idxCmd = MF_IDX_ANNUNCIATOR;
             szData = MF_SZ_ANNUNCIATOR;
             break;

        // below an unused command - ignored
        case MF_START_MF:
        case MF_UNCHECK_2E0:
        case MF_DISPLAY_ONOFF:
        default:
             szData = 0;
             break;
      }
      if(szData > 0)
      {
        tMF[idxCmd].cmd = data;
        tMF[idxCmd].dsz = szData;
      }
    }
    else
    {
      /*
       * if SYNC Logic Low(0), one or more data that corresponding to the command(from INA)
       * it depends on the previous "command" received
       */
      if(szData > 0)
      {
        // data are received in reverse order, we have to reorder them
        tMF[idxCmd].data[szData-1] = data;
        tMF[idxCmd].valid = MF_DATA_VALID;  // data are received.
        szData--;
      }
      else
      {
        spi_disable();
      }
    }
  }
}

//We should never pass here ...
ISR(BADISR_vect)
{
  //printf("???(BADISR_vect)\n");
}
/*
 * EOF
 */

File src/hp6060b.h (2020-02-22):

#ifndef HP6060B_H_
#define HP6060B_H_
/*
 * $Id: hp6060b.h 3:33 PM 12/1/2019 ssk  $
 *
 * HP 6060B Display protocol decoding.
 *
 * MIT License
 *
 * Copyright (c) 2019 ssk.
 *
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
*/
#define CTRL_PORT       PORTD
#define CTRL_DDR        DDRD
#define CTRL_INPUT      PIND
#define CTRL_PWO        2       // INT0 : Falling Edge
#define CTRL_SYNC       3       // INT1 : Any logical change
/*
* The command was originally 10bits LSB First,
* but since the first 2 bits are always 0 and atmel SPI is 8bit system
* Accordingly 8Bits is used here
* +-----+--------------+------------------+---------------+
* |SYNC#|command field |10bit(originally) |8bit(used hear)|
* +-----+--------------+-----+------------+----------+----+
* |    0|Select LCD    |0x3f0|0b1111110000|0b11111100|0xfc|
* |    1|Unknown       |0x2e0|0b1011100000|0b10111000|0xb8|
* |    2|A Register    |0x028|0b0000101000|0b00001010|0x0a|
* |    3|B Register    |0x068|0b0001101000|0b00011010|0x1a|
* |    4|Annunciator   |0x2f0|0b1011110000|0b10111100|0xbc|
* |    5|C Register    |0x0a8|0b0010101000|0b00101010|0x2a|
* |    6|Display On/Off|0x320|0b1100100000|0b11001000|0xc8|
* +-----+--------------+------------------+---------------+
*
* Remembering that bits are transmitted from least significant bit (LSB) to most significant bit (MSB),
* aka. LSB First
*/
// command field in message frame (order of transmission)
#define MF_START_MF          0xfc  // 0x3F0 start message frame (select the display)
#define MF_UNCHECK_2E0       0xb8  // 0x2E0 undocummented command (we will ignore it)
#define MF_REGISTER_A        0x0a  // 0x028 registers A for the 12 digits
#define MF_REGISTER_B        0x1a  // 0x068 registers B for the 12 digits
#define MF_ANNUNCIATOR       0xbc  // 0x2F0 the annunciators (eg the little arrows that are below the digits).
                                   // The annunciators will follow in the data frame ("INA" line):
                                   // there is one bit per annunciator, and the top right annunciator is transmitted first
#define MF_REGISTER_C        0x2a  // 0x0A8 registers C for the 12 digits
#define MF_DISPLAY_ONOFF     0xc8  // 0x320 toggle the display ON/OFF

// command index in message frame structure
#define MF_IDX_REGISTER_A    0      
#define MF_IDX_REGISTER_B    1      
#define MF_IDX_REGISTER_C    2      
#define MF_IDX_ANNUNCIATOR   3 
//#define MF_IDX_START_MF      4     // an unused command - ignored
//#define MF_IDX_UNCHECK_2E0   5     // an unused command - ignored
//#define MF_IDX_DISPLAY       6     // an unused command - ignored 

// data size in the each command field
#define MF_SZ_REGISTER_A     6
#define MF_SZ_REGISTER_B     6 
#define MF_SZ_REGISTER_C     6
#define MF_SZ_ANNUNCIATOR    2    
//#define MF_SZ_START_MF       1    // an unused - ignored  
//#define MF_SZ_UNCHECK_2E0    1    // an unused - ignored 
//#define MF_SZ_DISPLAY        1    // an unused - ignored 

#define isDataBusActive()   (bit_is_set(CTRL_INPUT, CTRL_PWO))
#define isDataBusIdle()     (bit_is_clear(CTRL_INPUT, CTRL_PWO))
#define isCommand()         (bit_is_set(CTRL_INPUT, CTRL_SYNC))
#define isData()            (bit_is_clear(CTRL_INPUT, CTRL_SYNC))

// Magic numbers
#define MF_SZ_COMMAND        4    // command count per message frame
#define MF_SZ_DATA           6    // max data count per each command
#define MF_MAX_DIGIT         12   
#define MF_DATA_VALID        1    // message frame are received (display ready)
#define MF_DATA_INVALID      0
#define MF_ANNUNCIATOR_CHAR  127  // '▼' Annunciator character code (system_5_5x7.h)
#define MF_PUNCT_NONE        32   // ' ' Punctuation character code (hp6060b_punct.h)
#define MF_PUNCT_COMMA       33   // ',' Punctuation character code (hp6060b_punct.h)
#define MF_PUNCT_DOT         34   // '.' Punctuation character code (hp6060b_punct.h)
#define MF_PUNCT_COLON       35   // ':' Punctuation character code (hp6060b_punct.h)

// message frame structure
typedef struct
{
  uint8_t cmd;
  uint8_t dsz;
  uint8_t data[MF_SZ_DATA];
  uint8_t valid;
} tMessageFrame;
        
#endif

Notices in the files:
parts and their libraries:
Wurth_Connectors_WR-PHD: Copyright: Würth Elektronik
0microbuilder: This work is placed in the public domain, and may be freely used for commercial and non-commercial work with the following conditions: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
